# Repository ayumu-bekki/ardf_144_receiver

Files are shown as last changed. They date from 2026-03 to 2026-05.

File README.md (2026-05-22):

# ARDF 144MHz Receiver

ESP32-C6ベースの144MHz帯ARDF (Amateur Radio Direction Finding) 用受信機プロジェクトです。
ハードウェアからファームウェア、ケース、アンテナ設計データまでを含んでいます。

## 概要

本プロジェクトはスーパーヘテロダイン方式を採用した144MHz帯ARDF競技用受信機です。
各種制御はXIAO ESP32C6で行い、局部発振器にSi5351Aを使用しています。

### 主な特徴・構成要素
- **XIAO ESP32C6**: メインコントローラ
- **Si5351A**: クロックジェネレータ（局部発振器 LO）
- **MCP4018**: デジタルポテンショメータによる電子ボリューム制御（Aカーブ対応）
- **SSD1306**: 128x32 OLEDディスプレイ搭載（周波数、プリアンプ状態、ボリュームなどを表示）
- カスタムPCB設計 (KiCad)
- 3Dプリント対応専用ケース設計 (FreeCAD / STEP)
- 144MHz帯3エレメント八木・宇田アンテナ設計 (FreeCAD)

## ディレクトリ構成

- `app/ardf_receiver/`: ESP-IDF ファームウェアソースコード (C++17)
- `antenna/`: 144MHz帯3エレメント八木アンテナ設計データ (FreeCAD)
- `case/`: 3Dプリント用ケース設計データ (FreeCAD / STEP)
- `pcb/`: カスタムプリント基板設計データおよびガーバーデータ (KiCad)

## 開発環境 (ファームウェア)

- **フレームワーク**: ESP-IDF (v6.0)
- **言語**: C++17

### ビルドと書き込み

```bash
cd app/ardf_receiver
# ESP-IDF環境のセットアップ (環境に応じて実行)
. $IDF_PATH/export.sh

# ビルド
idf.py build

# デバイスへの書き込みとシリアルモニタの起動
idf.py flash monitor
```

## ライセンス

本プロジェクトは [CERN Open Hardware Licence Version 2 – Permissive (CERN-OHL-P-2.0)](LICENSE) のもとで公開されています。
Copyright (c) 2026 Ayumu Bekki

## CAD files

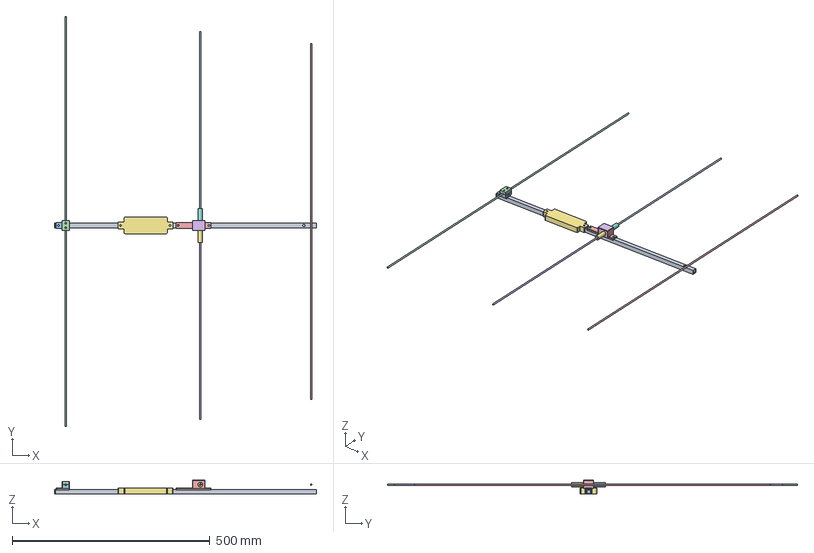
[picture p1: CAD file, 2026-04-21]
antenna/YagiUda3Ele144MHzForARDF.FCStd
662.0 x 1036.0 x 36.0 mm
Boom
DrivenElementBase
Cap
AntR
AntD1
AntDE_R
DEBase_R
DEBase_L
AntDE_L
DirectorBase
DirectorBottomV3
DirectorTopV3
DrivenElementCase
DrivenElementLid
ReceiverBase

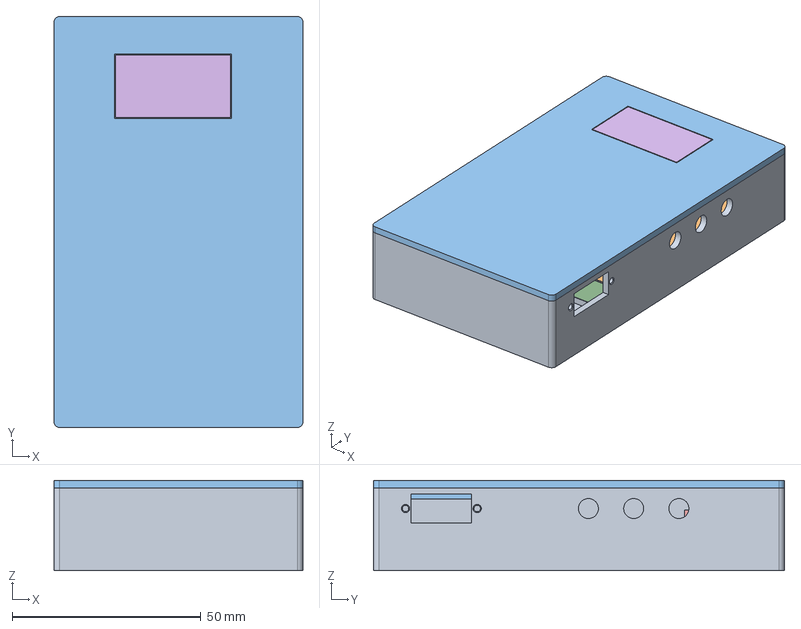
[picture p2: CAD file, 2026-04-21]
case/ardf_receiver_case.FCStd
66.0 x 109.0 x 24.0 mm
PCB
Lid
Sheld
DisplaySupport
DisplayWindow

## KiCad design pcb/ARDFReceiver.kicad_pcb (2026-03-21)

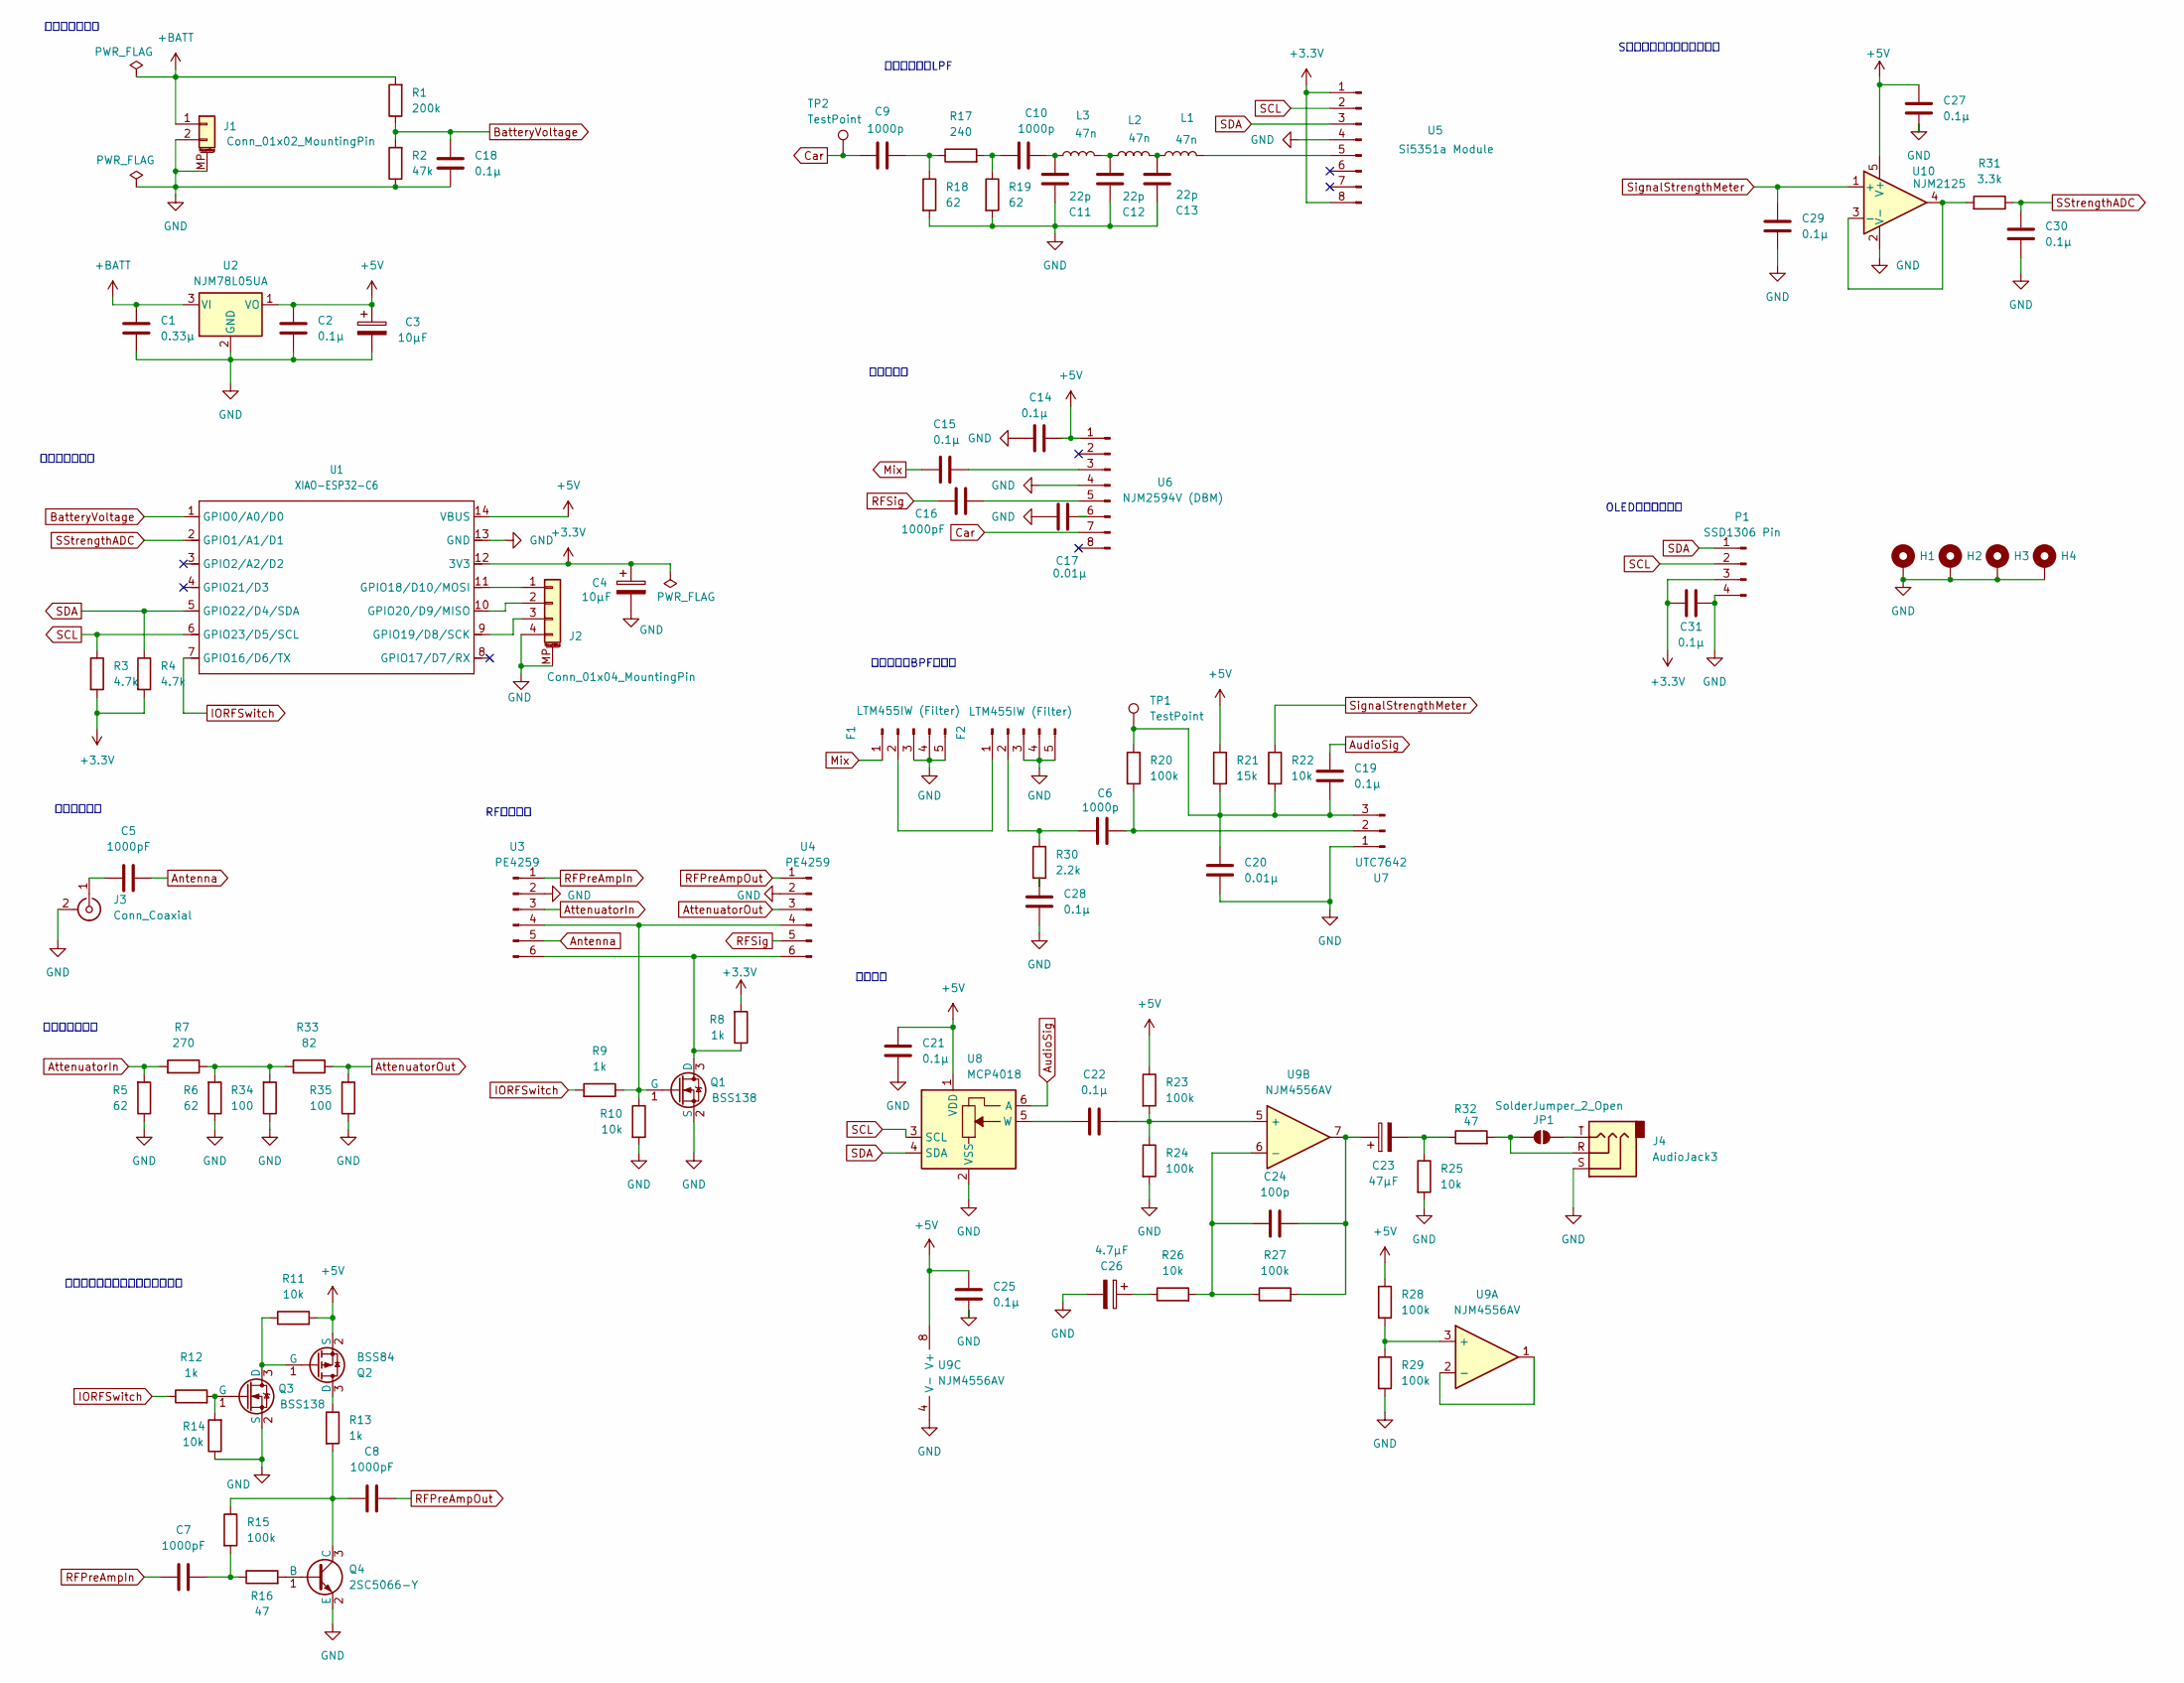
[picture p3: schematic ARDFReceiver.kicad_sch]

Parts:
C1: 0.33μ; C_0603_1608Metric_Pad1.08x0.95mm_HandSolder
C2, C14, C15, C18, C19, C21, C22, C25, C27, C28, C29, C30, C31: 0.1μ; C_0603_1608Metric_Pad1.08x0.95mm_HandSolder
C3, C4: 10μF; CP_Elec_4x5.8
C5, C7, C8, C16: 1000pF; C_0603_1608Metric_Pad1.08x0.95mm_HandSolder
C6, C9, C10: 1000p; C_0603_1608Metric_Pad1.08x0.95mm_HandSolder
C11, C12, C13: 22p; C_0603_1608Metric_Pad1.08x0.95mm_HandSolder
C17, C20: 0.01μ; C_0603_1608Metric_Pad1.08x0.95mm_HandSolder
C23: 47μF; CP_Elec_6.3x5.8
C24: 100p; C_0603_1608Metric_Pad1.08x0.95mm_HandSolder
C26: 4.7μF; CP_Elec_4x5.4
F1, F2: LTM455IW (Filter); LTM455IW
H1, H2, H3, H4: MountingHole_3.2mm_M3_Pad_Via
J1: Conn_01x02_MountingPin; JST_PH_B2B-PH-SM4-TB_1x02-1MP_P2.00mm_Vertical
J2: Conn_01x04_MountingPin; JST_PH_B4B-PH-SM4-TB_1x04-1MP_P2.00mm_Vertical
J3: Conn_Coaxial; SMA_S-063-49-TGG_EdgeMount_Horizontal
J4: AudioJack3; Jack_3.5mm_Switronic_ST-005-G_horizontal
JP1: SolderJumper_2_Open; SolderJumper-2_P1.3mm_Open_TrianglePad1.0x1.5mm
L1, L2, L3: 47n; L_0805_2012Metric_Pad1.05x1.20mm_HandSolder
P1: SSD1306 Pin; PinSocket_1x04_P2.54mm_Vertical
Q1, Q3: BSS138; SOT-23-3
Q2: BSS84; SOT-23-3
Q4: 2SC5066-Y; SOT-523_handsold
R1: 200k; R_0603_1608Metric_Pad0.98x0.95mm_HandSolder
R2: 47k; R_0603_1608Metric_Pad0.98x0.95mm_HandSolder
R3, R4: 4.7k; R_0603_1608Metric_Pad0.98x0.95mm_HandSolder
R5, R6, R18, R19: 62; R_0603_1608Metric_Pad0.98x0.95mm_HandSolder
R7: 270; R_0603_1608Metric_Pad0.98x0.95mm_HandSolder
R8, R9, R12, R13: 1k; R_0603_1608Metric_Pad0.98x0.95mm_HandSolder
R10, R11, R14, R22, R25, R26: 10k; R_0603_1608Metric_Pad0.98x0.95mm_HandSolder
R15, R20, R23, R24, R27, R28, R29: 100k; R_0603_1608Metric_Pad0.98x0.95mm_HandSolder
R16: 47; R_0603_1608Metric
R17: 240; R_0603_1608Metric_Pad0.98x0.95mm_HandSolder
R21: 15k; R_0603_1608Metric_Pad0.98x0.95mm_HandSolder
R30: 2.2k; R_0603_1608Metric_Pad0.98x0.95mm_HandSolder
R31: 3.3k; R_0603_1608Metric_Pad0.98x0.95mm_HandSolder
R32: 47; R_0603_1608Metric_Pad0.98x0.95mm_HandSolder
R33: 82; R_0603_1608Metric_Pad0.98x0.95mm_HandSolder
R34, R35: 100; R_0603_1608Metric_Pad0.98x0.95mm_HandSolder
TP1, TP2: TestPoint; TestPoint_Pad_D1.0mm
U1: XIAO-ESP32-C6; XIAO-ESP32C6-DIP
U2: NJM78L05UA; SOT-89-3_Handsoldering_Thirmo_Via
U3, U4: PE4259; SOT-363_SC-70-6_Handsoldering
U5: Si5351a Module; DIP-8_W7.62mm
U6: NJM2594V (DBM); TSSOP-8_4.4x3mm_P0.65mm
U7: UTC7642; TO-92L_Inline
U8: MCP4018; SOT-363_SC-70-6_Handsoldering
U9: NJM4556AV; TSSOP-8_4.4x3mm_P0.65mm
U10: NJM2125; SOT-23-5_HandSoldering

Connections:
+3.3V: C4.1, C31.1, P1.3, R3.2, R4.2, R8.2, U1.12 (3V3), U5.1, U5.8
+5V: C2.1, C3.1, C14.1, C21.1, C25.1, C27.1, Q2.2 (S), R11.2, R21.1, R23.1, R28.1, U1.14 (VBUS), U2.1 (VO), U6.1, U8.1 (VDD), U9.8 (V+), U10.5 (V+)
+BATT: C1.1, J1.1, R1.2, U2.3 (VI)
Antenna: C5.2, U3.5
AttenuatorIn: R5.2, R7.2, U3.3
AttenuatorOut: R33.1, R35.2, U4.3
AudioSig: C19.1, U8.6 (A)
BatteryVoltage: C18.1, R1.1, R2.2, U1.1 (GPIO0/A0/D0)
Car: C9.2, TP2.1, U6.7
GND: C1.2, C2.2, C3.2, C4.2, C11.1, C12.1, C13.1, C14.2, C17.2, C18.2, C20.2, C21.2, C25.2, C26.2, C27.2, C28.2, C29.1, C30.1, C31.2, F1.3, F1.4, F1.5, F2.3, F2.4, F2.5, H1.1, H2.1, H3.1, H4.1, J1.2, J1.MP (MountPin), J2.4, J2.MP (MountPin), J3.2 (Ext), J4.S, P1.4, Q1.2 (S), Q3.2 (S), Q4.2 (E), R2.1, R5.1, R6.1, R10.2, R14.1, R18.2, R19.2, R24.2, R25.2, R29.2, R34.1, R35.1, U1.13 (GND), U2.2 (GND), U3.2, U4.2, U5.4, U6.4, U7.1, U8.2 (VSS), U9.4 (V-), U10.2 (V-)
IORFSwitch: R9.2, R12.1, U1.7 (GPIO16/D6/TX)
Mix: C15.2, F1.1
unnamed: C7.2, R15.2, R16.1
unnamed: C9.1, R17.1, R18.1
unnamed: C10.1, C11.2, L3.1
unnamed: C10.2, R17.2, R19.1
unnamed: C12.2, L2.1, L3.2
unnamed: C13.2, L1.1, L2.2
unnamed: C23.1, C24.2, R27.2, U9.7
unnamed: C23.2, R25.1, R32.1
unnamed: C26.1, R26.1
unnamed: C28.1, R30.2
unnamed: F1.2, F2.1
unnamed: C6.1, F2.2, R30.1
unnamed: J2.1, U1.11 (GPIO18/D10/MOSI)
unnamed: J2.2, U1.10 (GPIO20/D9/MISO)
unnamed: J2.3, U1.9 (GPIO19/D8/SCK)
unnamed: C5.1, J3.1 (In)
unnamed: J4.R, JP1.1 (A), R32.2
unnamed: J4.T, JP1.2 (B)
unnamed: Q1.3 (D), R8.1, U3.6, U4.6
unnamed: Q1.1 (G), R9.1, R10.1, U3.4, U4.4
unnamed: Q2.3 (D), R13.1
unnamed: Q2.1 (G), Q3.3 (D), R11.1
unnamed: Q3.1 (G), R12.2, R14.2
unnamed: Q4.1 (B), R16.2
unnamed: C8.1, Q4.3 (C), R13.2, R15.1
unnamed: R6.2, R7.1, R33.2, R34.2
unnamed: L1.2, U5.5
unnamed: C15.1, U6.3
unnamed: C16.2, U6.5
unnamed: C17.1, U6.6
unnamed: C6.2, R20.2, U7.2
unnamed: C19.2, C20.1, R20.1, R21.2, R22.2, TP1.1, U7.3
unnamed: C22.1, U8.5 (W)
unnamed: R28.2, R29.1, U9.3 (+)
unnamed: U9.1, U9.2 (-)
unnamed: C22.2, R23.2, R24.1, U9.5 (+)
unnamed: C24.1, R26.2, R27.1, U9.6 (-)
unnamed: R31.2, U10.3 (-), U10.4
RFPreAmpIn: C7.1, U3.1
RFPreAmpOut: C8.2, U4.1
RFSig: C16.1, U4.5
SCL: P1.2, R3.1, U1.6 (GPIO23/D5/SCL), U5.2, U8.3 (SCL)
SDA: P1.1, R4.1, U1.5 (GPIO22/D4/SDA), U5.3, U8.4 (SDA)
SStrengthADC: C30.2, R31.1, U1.2 (GPIO1/A1/D1)
SignalStrengthMeter: C29.2, R22.1, U10.1 (+)

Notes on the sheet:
正弦波生成・LPF
プリアンプ・プリアンプ駆動回路
音声増幅
周波数混合
RFスイッチ
制御用マイコン
OLEDディスプレイ
アンテナ入力
中間周波数BPF・検波
アッテネーター
Sメーター用バッファアンプ
電源・電圧監視

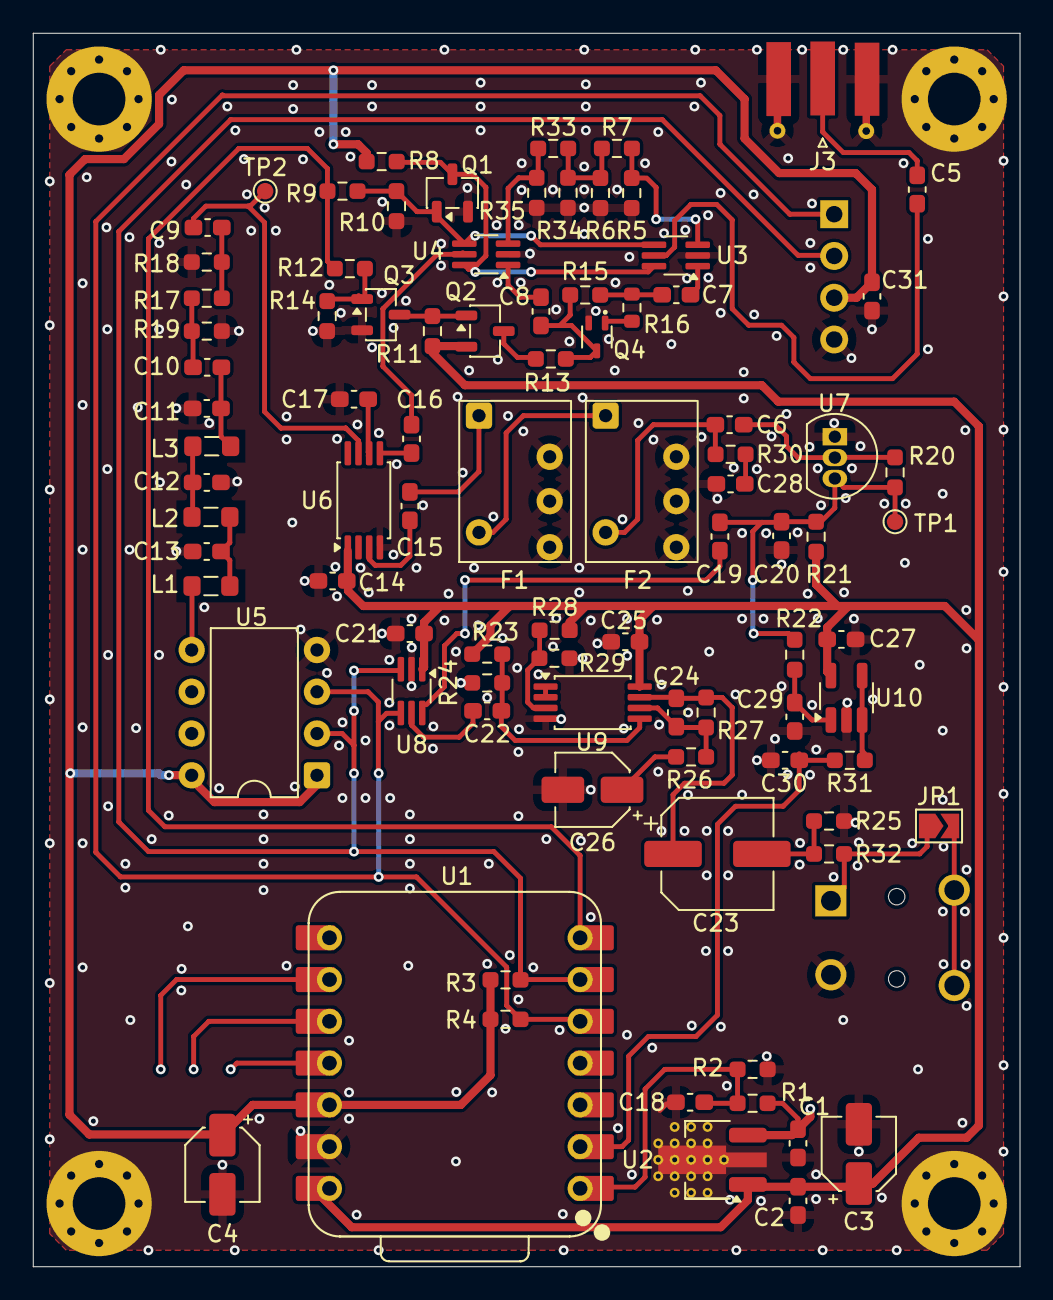
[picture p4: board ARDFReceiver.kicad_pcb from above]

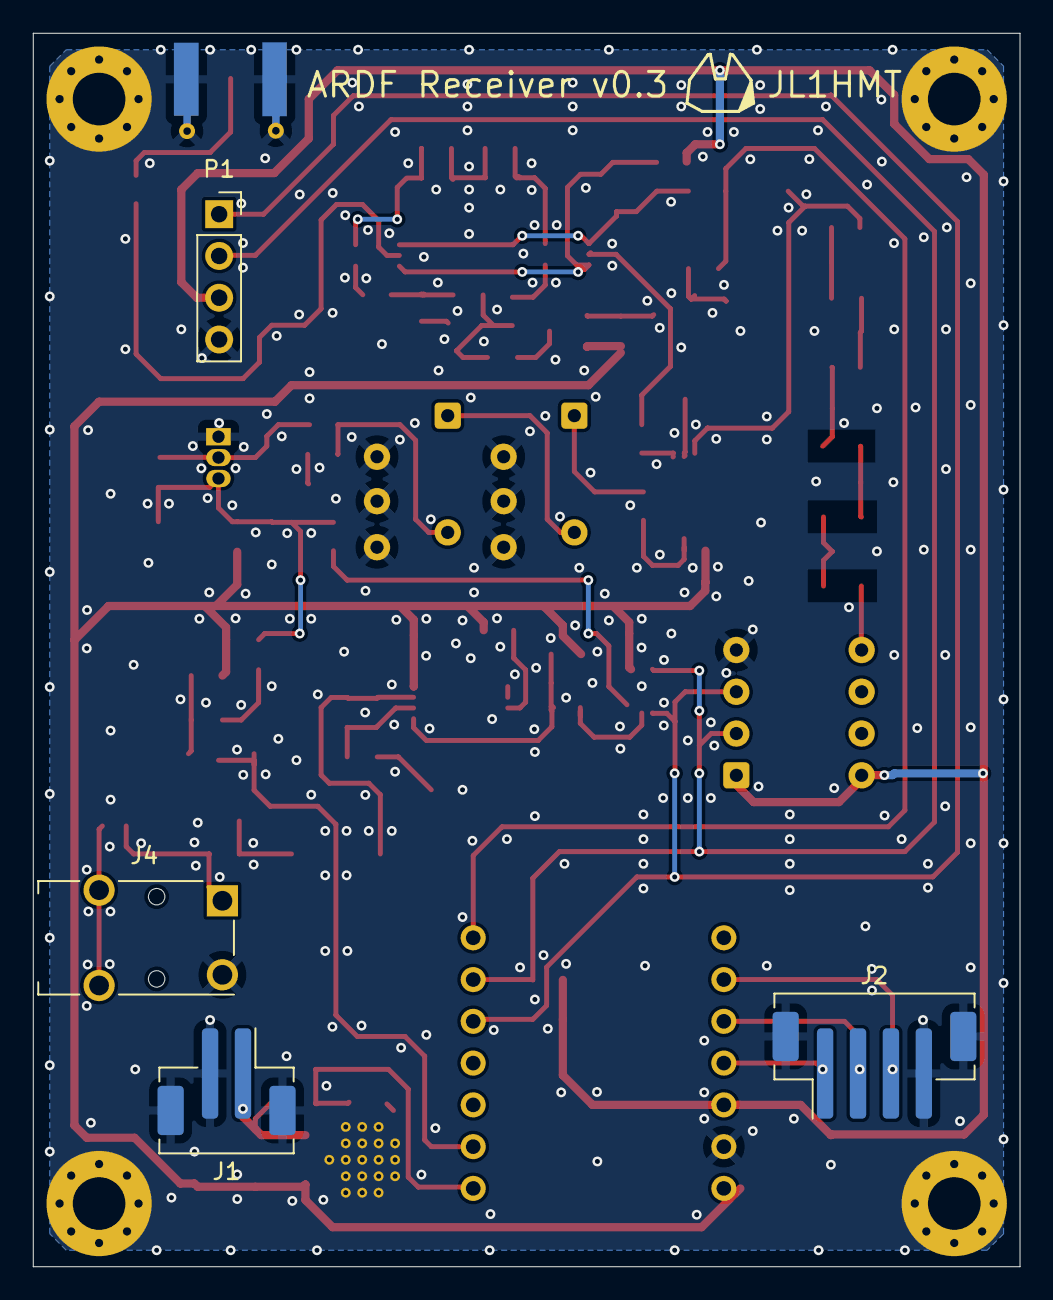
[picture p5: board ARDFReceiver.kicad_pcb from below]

Board: 2 copper layers, 60.0 x 75.0 mm, 97 parts (4 on the bottom side), 57 nets.

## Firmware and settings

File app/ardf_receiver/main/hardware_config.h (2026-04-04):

#ifndef HARDWARE_CONFIG_H_
#define HARDWARE_CONFIG_H_
// ESP32 B-Fox Receiver
// (C)2025 bekki.jp
// Hardware Configuration Constants

#include "driver/gpio.h"
#include "driver/i2c.h"
#include "freertos/FreeRTOS.h"
#include "xiao_esp32c6_pin.h"

namespace receiver_system {
namespace hardware_config {

// ============================================================================
// GPIO Pin Assignments (Application-specific mappings)
// ============================================================================

// I2C Bus Pins
constexpr gpio_num_t kI2cSdaPin = xiao_esp32c6_pin::kSda;
constexpr gpio_num_t kI2cSclPin = xiao_esp32c6_pin::kScl;

// Preamp Control
constexpr gpio_num_t kPreampEnablePin = xiao_esp32c6_pin::kD6;

// Button Inputs
constexpr gpio_num_t kButtonSelectPin = xiao_esp32c6_pin::kD10; 
constexpr gpio_num_t kButtonPlusPin = xiao_esp32c6_pin::kD9;
constexpr gpio_num_t kButtonMinusPin = xiao_esp32c6_pin::kD8;

// ADC Input
constexpr gpio_num_t kBatteryVoltagePin = xiao_esp32c6_pin::kA0;
constexpr gpio_num_t kSignalStrengthMeterPin = xiao_esp32c6_pin::kA1;

// ============================================================================
// Battery Monitoring Configuration
// ============================================================================

// Battery voltage monitoring interval (milliseconds)
constexpr uint32_t kBatteryMonitorIntervalMs = 30000;  // 30 seconds

// Number of ADC samples to average per measurement
constexpr int kBatteryAdcSampleCount = 5;

// Voltage divider circuit constants
// Battery voltage is divided by R1 and R2
// V_adc = V_battery × (R2 / (R1 + R2))
constexpr float kBatteryVoltageDividerR1 = 200000.0f;  // 200kΩ (battery side)
constexpr float kBatteryVoltageDividerR2 = 47000.0f;   // 47kΩ (GND side)

// ADC offset correction (mV): compensates for ESP32-C6 ADC systematic error
// Adjust this value based on measured vs. actual voltage comparison
constexpr int kBatteryAdcOffsetCorrectionMv = 0;

// ============================================================================
// Signal Strength Meter Configuration
// ============================================================================

// Signal meter monitoring interval (milliseconds)
constexpr uint32_t kSignalMeterIntervalMs = 100;  // 10 readings/sec

// Peak hold time (milliseconds)
constexpr uint32_t kSignalMeterPeakHoldMs = 3000;  // 3 seconds

// S-meter calibration (AGC逆特性: 信号強→電圧低)
// 無信号時の上限電圧（この値以上は 0% とみなす）
constexpr int kSmeterAgcNoSignalVoltage = 1075;  // mV
// 強電界時の下限電圧（この値以下は 100% とクリップ）
constexpr int kSmeterAgcFullSignalVoltage = 920;  // mV

// EMAフィルタ平滑化係数 (0.0〜1.0)
// 小さいほど平滑・応答遅延増、大きいほど追従速・ノイズ多
// 推奨: 0.2（応答5サイクル≒500ms）
constexpr float kSmeterEmaAlpha = 0.2f;

// S値 (0-9) 変換定数
// signal_strength (0-100) を S値 (0-9) に変換: s = signal / kSmeterSValueDivisor
constexpr int kSmeterSValueDivisor = 11;
constexpr int kSmeterSValueMax = 9;

// S-meter パーセント基準値 (0-100%)
constexpr int kSmeterPercentMax = 100;

// Signal Meter ADC サンプリング間隔 (ms, サンプル間)
constexpr uint32_t kSignalMeterSampleIntervalMs = 1;

// Signal Meter ADC サンプル数
constexpr int kSignalMeterAdcSampleCount = 10;

// ============================================================================
// I2C Device Timing
// ============================================================================

// MCP4018 電源投入後の安定化待機時間 (ms)
constexpr uint32_t kMcp4018PowerOnDelayMs = 50;

// MCP4018 I2C リトライ前の待機時間 (ms)
constexpr uint32_t kMcp4018RetryDelayMs = 10;

// I2Cデバイス初期化後のバス安定化待機時間 (ms)
constexpr uint32_t kI2cBusStabilizeDelayMs = 100;

// メインループスリープ時間 (ms)
constexpr uint32_t kMainLoopSleepMs = 1000;

// ============================================================================
// I2C Configuration
// ============================================================================

constexpr i2c_port_t kI2cPort = I2C_NUM_0;
constexpr uint32_t kI2cFrequencyHz = 400000;

// I2C Timeout (in FreeRTOS ticks)
constexpr TickType_t kI2cTimeoutTicks = 1000 / portTICK_PERIOD_MS;

// ============================================================================
// Timing Constants
// ============================================================================

// Display update polling interval (milliseconds)
constexpr uint32_t kDisplayUpdateIntervalMs = 200;

// GPIO watch task timer interval (microseconds)
constexpr uint32_t kGpioPollingIntervalUs = 5000;  // 5ms

// GPIO watch queue timeout (FreeRTOS ticks)
constexpr TickType_t kGpioQueueTimeoutTicks = 1000 / portTICK_PERIOD_MS;

// ============================================================================
// GPIO Input Configuration
// ============================================================================

// Debounce: number of consecutive reads required for stable edge detection
constexpr int32_t kDebounceEdgeCount = 3;
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

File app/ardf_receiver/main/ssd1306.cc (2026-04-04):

#include "ssd1306.h"

#include <freertos/FreeRTOS.h>
#include <freertos/task.h>
#include <rom/ets_sys.h>

#include <algorithm>
#include <memory>

#include "i2c_util.h"
#include "logger.h"

namespace receiver_system {

// 5x7フォントデータ（ASCII 32-126）
static const uint8_t font5x7[][5] = {
    {0x00, 0x00, 0x00, 0x00, 0x00},  // ' '
    {0x00, 0x00, 0x5F, 0x00, 0x00},  // '!'
    {0x00, 0x07, 0x00, 0x07, 0x00},  // '"'
    {0x14, 0x7F, 0x14, 0x7F, 0x14},  // '#'
    {0x24, 0x2A, 0x7F, 0x2A, 0x12},  // '$'
    {0x23, 0x13, 0x08, 0x64, 0x62},  // '%'
    {0x36, 0x49, 0x55, 0x22, 0x50},  // '&'
    {0x00, 0x05, 0x03, 0x00, 0x00},  // '''
    {0x00, 0x1C, 0x22, 0x41, 0x00},  // '('
    {0x00, 0x41, 0x22, 0x1C, 0x00},  // ')'
    {0x14, 0x08, 0x3E, 0x08, 0x14},  // '*'
    {0x08, 0x08, 0x3E, 0x08, 0x08},  // '+'
    {0x00, 0x50, 0x30, 0x00, 0x00},  // ','
    {0x08, 0x08, 0x08, 0x08, 0x08},  // '-'
    {0x00, 0x60, 0x60, 0x00, 0x00},  // '.'
    {0x20, 0x10, 0x08, 0x04, 0x02},  // '/'
    {0x3E, 0x51, 0x49, 0x45, 0x3E},  // '0'
    {0x00, 0x42, 0x7F, 0x40, 0x00},  // '1'
    {0x42, 0x61, 0x51, 0x49, 0x46},  // '2'
    {0x21, 0x41, 0x45, 0x4B, 0x31},  // '3'
    {0x18, 0x14, 0x12, 0x7F, 0x10},  // '4'
    {0x27, 0x45, 0x45, 0x45, 0x39},  // '5'
    {0x3C, 0x4A, 0x49, 0x49, 0x30},  // '6'
    {0x01, 0x71, 0x09, 0x05, 0x03},  // '7'
    {0x36, 0x49, 0x49, 0x49, 0x36},  // '8'
    {0x06, 0x49, 0x49, 0x29, 0x1E},  // '9'
    {0x00, 0x36, 0x36, 0x00, 0x00},  // ':'
    {0x00, 0x56, 0x36, 0x00, 0x00},  // ';'
    {0x08, 0x14, 0x22, 0x41, 0x00},  // '<'
    {0x14, 0x14, 0x14, 0x14, 0x14},  // '='
    {0x00, 0x41, 0x22, 0x14, 0x08},  // '>'
    {0x02, 0x01, 0x51, 0x09, 0x06},  // '?'
    {0x32, 0x49, 0x79, 0x41, 0x3E},  // '@'
    {0x7E, 0x11, 0x11, 0x11, 0x7E},  // 'A'
    {0x7F, 0x49, 0x49, 0x49, 0x36},  // 'B'
    {0x3E, 0x41, 0x41, 0x41, 0x22},  // 'C'
    {0x7F, 0x41, 0x41, 0x22, 0x1C},  // 'D'
    {0x7F, 0x49, 0x49, 0x49, 0x41},  // 'E'
    {0x7F, 0x09, 0x09, 0x09, 0x01},  // 'F'
    {0x3E, 0x41, 0x49, 0x49, 0x7A},  // 'G'
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
};

SSD1306::SSD1306()
    : dev_handle_(nullptr), i2c_address_(0), buffer_(), prev_buffer_() {}

SSD1306::~SSD1306() {
  if (dev_handle_) {
    i2c_master_bus_rm_device(dev_handle_);
    dev_handle_ = nullptr;
  }
}

void SSD1306::Setup(const uint8_t address) {
  i2c_address_ = address;

  // Get the I2C bus handle
  i2c_master_bus_handle_t bus_handle = i2c_util::GetBusHandle();
  if (!bus_handle) {
    ESP_LOGE(kTag, "I2C bus not initialized");
    return;
  }

  // Add device to the bus
  i2c_device_config_t dev_config = {};
  dev_config.dev_addr_length = I2C_ADDR_BIT_LEN_7;
  dev_config.device_address = address;
  dev_config.scl_speed_hz = i2c_util::kI2cMasterFrequencyHz;

  esp_err_t ret =
      i2c_master_bus_add_device(bus_handle, &dev_config, &dev_handle_);
  if (ret != ESP_OK) {
    ESP_LOGE(kTag, "Failed to add SSD1306 device: %s", esp_err_to_name(ret));
    return;
  }

  // バッファを確保
  buffer_.resize(kBufferSize, 0x00);
  prev_buffer_.resize(kBufferSize, 0xFF);  // Force first display

  if (buffer_.empty() || prev_buffer_.empty()) {
    ESP_LOGE(kTag, "Failed to allocate display buffers");
    return;
  }

  InitializeDisplay();
}

void SSD1306::InitializeDisplay() {
  // 初期化シーケンス（SSD1306データシート準拠）
  WriteCommand(kCmdDisplayOff);

  WriteCommand(kCmdSetDisplayClockDiv);
  WriteCommand(kInitClockDiv);  // 高周波設定（可聴域ノイズ回避）

  WriteCommand(kCmdSetMultiplex);
  WriteCommand(kHeight - 1);  // 32-1=31

  WriteCommand(kCmdSetDisplayOffset);
  WriteCommand(0x00);  // オフセットなし

  WriteCommand(kCmdSetStartLine | 0x00);  // スタートライン = 0

  WriteCommand(kCmdChargePump);
  WriteCommand(kInitChargePumpOn);  // チャージポンプを有効化

  WriteCommand(kCmdMemoryMode);
  WriteCommand(kInitMemoryMode);  // 水平アドレッシングモード

  WriteCommand(kCmdSegRemap | kInitSegmentRemap);  // セグメントリマップ

  WriteCommand(kCmdComScanDec);  // COM出力スキャン方向

  WriteCommand(kCmdSetCompins);
  WriteCommand(kInitCompinsConfig);  // 128x32用の設定

  WriteCommand(kCmdSetContrast);
  WriteCommand(kInitContrast);  // コントラスト

  WriteCommand(kCmdSetPrecharge);
  WriteCommand(kInitPrecharge);  // プリチャージ期間

  WriteCommand(kCmdSetVcomDetect);
  WriteCommand(kInitVcomhDeselect);  // VCOMH電圧

  WriteCommand(kCmdDisplayAllOnResume);
  WriteCommand(kCmdNormalDisplay);
  WriteCommand(kCmdDisplayOn);

  ESP_LOGI(kTag, "SSD1306 initialized (128x32)");
}

void SSD1306::ClearDisplay() {
  std::fill(buffer_.begin(), buffer_.end(), 0x00);
}

void SSD1306::Display() {
  // Skip I2C transfer if buffer unchanged
  if (buffer_ == prev_buffer_) {
    return;
  }
  WriteCommand(kCmdColumnAddr);
  WriteCommand(0);
  WriteCommand(kColumnEndAddr);

  WriteCommand(kCmdPageAddr);
  WriteCommand(0);
  WriteCommand(kPageEndAddr);

  WriteData(buffer_.data(), kBufferSize);
  prev_buffer_ = buffer_;
}

void SSD1306::SetPixel(int16_t x, int16_t y, bool color) {
  if (x < 0 || x >= kWidth || y < 0 || y >= kHeight) {
    return;
  }

  if (color) {
    buffer_[x + (y >> kPixelByteShift) * kWidth] |= (1 << (y & kPixelBitMask));
  } else {
    buffer_[x + (y >> kPixelByteShift) * kWidth] &= ~(1 << (y & kPixelBitMask));
  }
}

void SSD1306::DrawLine(int16_t x0, int16_t y0, int16_t x1, int16_t y1,
                       bool color) {
  int16_t steep = abs(y1 - y0) > abs(x1 - x0);
  if (steep) {
    std::swap(x0, y0);
    std::swap(x1, y1);
  }

  if (x0 > x1) {
    std::swap(x0, x1);
    std::swap(y0, y1);
  }

  int16_t dx = x1 - x0;
  int16_t dy = abs(y1 - y0);

  int16_t err = dx / 2;
  int16_t ystep = (y0 < y1) ? 1 : -1;

  for (; x0 <= x1; x0++) {
    if (steep) {
      SetPixel(y0, x0, color);
    } else {
      SetPixel(x0, y0, color);
    }
    err -= dy;
    if (err < 0) {
      y0 += ystep;
      err += dx;
    }
  }
}

void SSD1306::DrawRect(int16_t x, int16_t y, int16_t w, int16_t h, bool color) {
  DrawLine(x, y, x + w - 1, y, color);
  DrawLine(x + w - 1, y, x + w - 1, y + h - 1, color);
  DrawLine(x + w - 1, y + h - 1, x, y + h - 1, color);
  DrawLine(x, y + h - 1, x, y, color);
}

void SSD1306::FillRect(int16_t x, int16_t y, int16_t w, int16_t h, bool color) {
  for (int16_t i = x; i < x + w; i++) {
    for (int16_t j = y; j < y + h; j++) {
      SetPixel(i, j, color);
    }
  }
}

void SSD1306::DrawChar(int16_t x, int16_t y, char c, bool color, uint8_t size) {
  if (c < kFontCharMin || c > kFontCharMax) {
    c = kFontCharMin;  // 範囲外は空白に
  }

  const uint8_t* glyph = font5x7[c - kFontCharMin];

  for (uint8_t i = 0; i < kFontWidth; i++) {
    uint8_t line = glyph[i];
    for (uint8_t j = 0; j < kFontHeight; j++) {
      if (line & 0x01) {
        if (size == 1) {
          SetPixel(x + i, y + j, color);
        } else {
          FillRect(x + i * size, y + j * size, size, size, color);
        }
      }
      line >>= 1;
    }
  }
}
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

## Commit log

2026-03-09 Adjust positions of 3.5mm Jack and Solder Jumper
    [ARDFReceiver.kicad_pcb]
2026-03-21 アンテナ3Dデータ追加 CADデータ更新 Sメータ修正
    [ARDFReceiver-B_Cu.gbr, ARDFReceiver-B_Mask.gbr, ARDFReceiver-B_Silkscreen.gbr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]
2026-03-22 ケースの追加
    [ardf_receiver_case.FCStd]
2026-03-30 ケースの修正と、ボタンのIO変更
    [ardf_receiver_case.FCStd]
2026-04-04 ボタン制御の修正 esp-idf6.0対応(I2C通信問題対応のため)
2026-04-21 CADデータ更新
    [YagiUda3Ele144MHzForARDF.FCStd, ardf_receiver_case.FCStd]
2026-05-22 ライセンスをCERN-OHL-P v2 に変更
